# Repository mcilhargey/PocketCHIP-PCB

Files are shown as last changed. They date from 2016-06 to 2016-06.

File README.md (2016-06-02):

# Source Files
PocketC.H.I.P. is designed using Eagle CAD!
# PocketCHIP-PCB

PocketC.H.I.P. = v1.0

#License
<br />This work is licensed under a <a rel="license" href="http://creativecommons.org/licenses/by-sa/3.0/us/">Creative Commons Attribution-ShareAlike 3.0 United States License</a>.

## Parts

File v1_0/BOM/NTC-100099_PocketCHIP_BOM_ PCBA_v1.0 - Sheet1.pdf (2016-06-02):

| | | | PCBA Components
NTC PN | QTY | PARTS | VALUE | DESCRIPTION | FOOTPRINT | TOLERANCE | MFG | MFG Part Number
100313 | 2 | R1, R9 | 100K | RES THICK FILM SMD 100K Ohm 1/16W 5% RoHS 0603 | R0603 | ±5% | YAGEO | RC0603JR-07100KL
100314 | 6 | C2, C3, C6, C8, C9, C10 | 0.1uF | CAP CER 0.1UF 16V X7R 0603 | C0603 | ±10% | YAGEO | CC0603KRX7R7BB104
100315 | 3 | C4, C5, C7 | 10uF | CAP CER 10UF 50V X5R 1206 | C1206 | ±10% | SAMSUNG | CL31A106KBHNNNE
100318 | 2 | R7, R11 | 10K | RES SMD 10K OHM 5% 1/10W 0603 | R0603 | ±5% | PANASONIC | ERJ-3GEYJ103V
100319 | 1 | R3 | 11.5K | RES SMD 11.5K OHM 1% 1/10W 0603 | R0603 | ±1% | YAGEO | RC0603FR-0711K5L
100333 | 1 | R2 | 196K | RES SMD 196K OHM 1% 1/10W 0603 | R0603 | ±1% | YAGEO | RC0603FR-07196KL
100321 | 7 | R4, R5, R6, R10, R12, R16, R17 | 4.7K | RES SMD 4.7K OHM 5% 1/10W 0603 | R0603 | ±5% | PANASONIC | ERJ-3GEYJ472V
100323 | 1 | C1 | 220pF | CAP CER 220PF 50V NPO 0603 | C0603 | ±5% | YAGEO | CL10C221JB8NNNC
100332 | 1 | R13 | 1.2K | RES SMD 1.2K OHM 5% 1/10W 0603 | R0603 | ±5% | YAGEO | RC0603JR-071K2L
100250 | 2 | U13, U14 | 98401-801-40LF | Bergstik 40pin Board Guide Header | Headers | - | FCI | 带柱2*20pin贴片
100191 | 1 | U3 | DS2431P | IC, 1024-Bit, 1-Wire EEPROM, TSOC6 | TSOC6 | - | MAXIM | DS2431P+T&R
100220 | 1 | X1 | FH12-40S-0.5SH | CON ffc smd, bottom contact 40pos, 0.50mm R/A | FFC | - | FCI | 国产fpc 0.5 40pin
100193 | 1 | U1 | LMR62421 | dc/dc step up, 2.1A, 1.6mhz, SOT-23-5 | SOT23-5 | - | TI | LMR62421XMFE/NOPB
100195 | 1 | J3 | S2B-PH-SM4-TB | 2 pin con, 2MM RA, SMD | S2B-PH-SM4-TB | - | JST | 国产ph2.0
100196 | 1 | L1 | SRN6045-100M | power inductor 10uH 2.5A 58.6 mohm | SRN6045 | ±20% | BOURNS | 国产SPN6045-100M
100197 | 1 | U2 | TCA8418RTWR | Keypad/IO I2C expander, 8 rows 10 columns | WQFN24 | - | TI | TCA8418RTWR
100198 | 1 | D1 | B240A | DIODE SMD General Purpose 400V 1A 1.4W RoHS DO-214A | DO-214AC | - | DIODES | B240A-13-F
100338 | 17 | ESD1-17 | SESD3.3 | TVS DIODE 3.3VWM 10.9VC SOD523 | SOD523 | | - | SESD5Z3.3
100329 | 2 | Q3, Q4 | dmg3415u | MOSFET P-CH 20V 3.7A SOT23-3 | SOT-23-3 | - | DIODES | DMG3415U
100331 | 1 | Q1 | PDTC114YU | TRANS PREBIAS PNP 200MW UMT3 | SOT-323 | - | NXP | PDTC114YU115
100330 | 1 | Q2 | PDTA114YU115 | TRANS PREBIAS NPN 200MW UMT3 | SOT-323 | - | NXP | PDTA114YU115

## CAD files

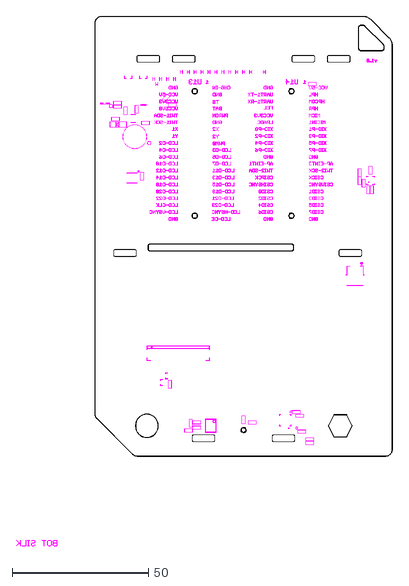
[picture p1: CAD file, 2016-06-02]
v1_0/DXF/PocketCHIP-v1.0.dxf
138.3 x 194.8

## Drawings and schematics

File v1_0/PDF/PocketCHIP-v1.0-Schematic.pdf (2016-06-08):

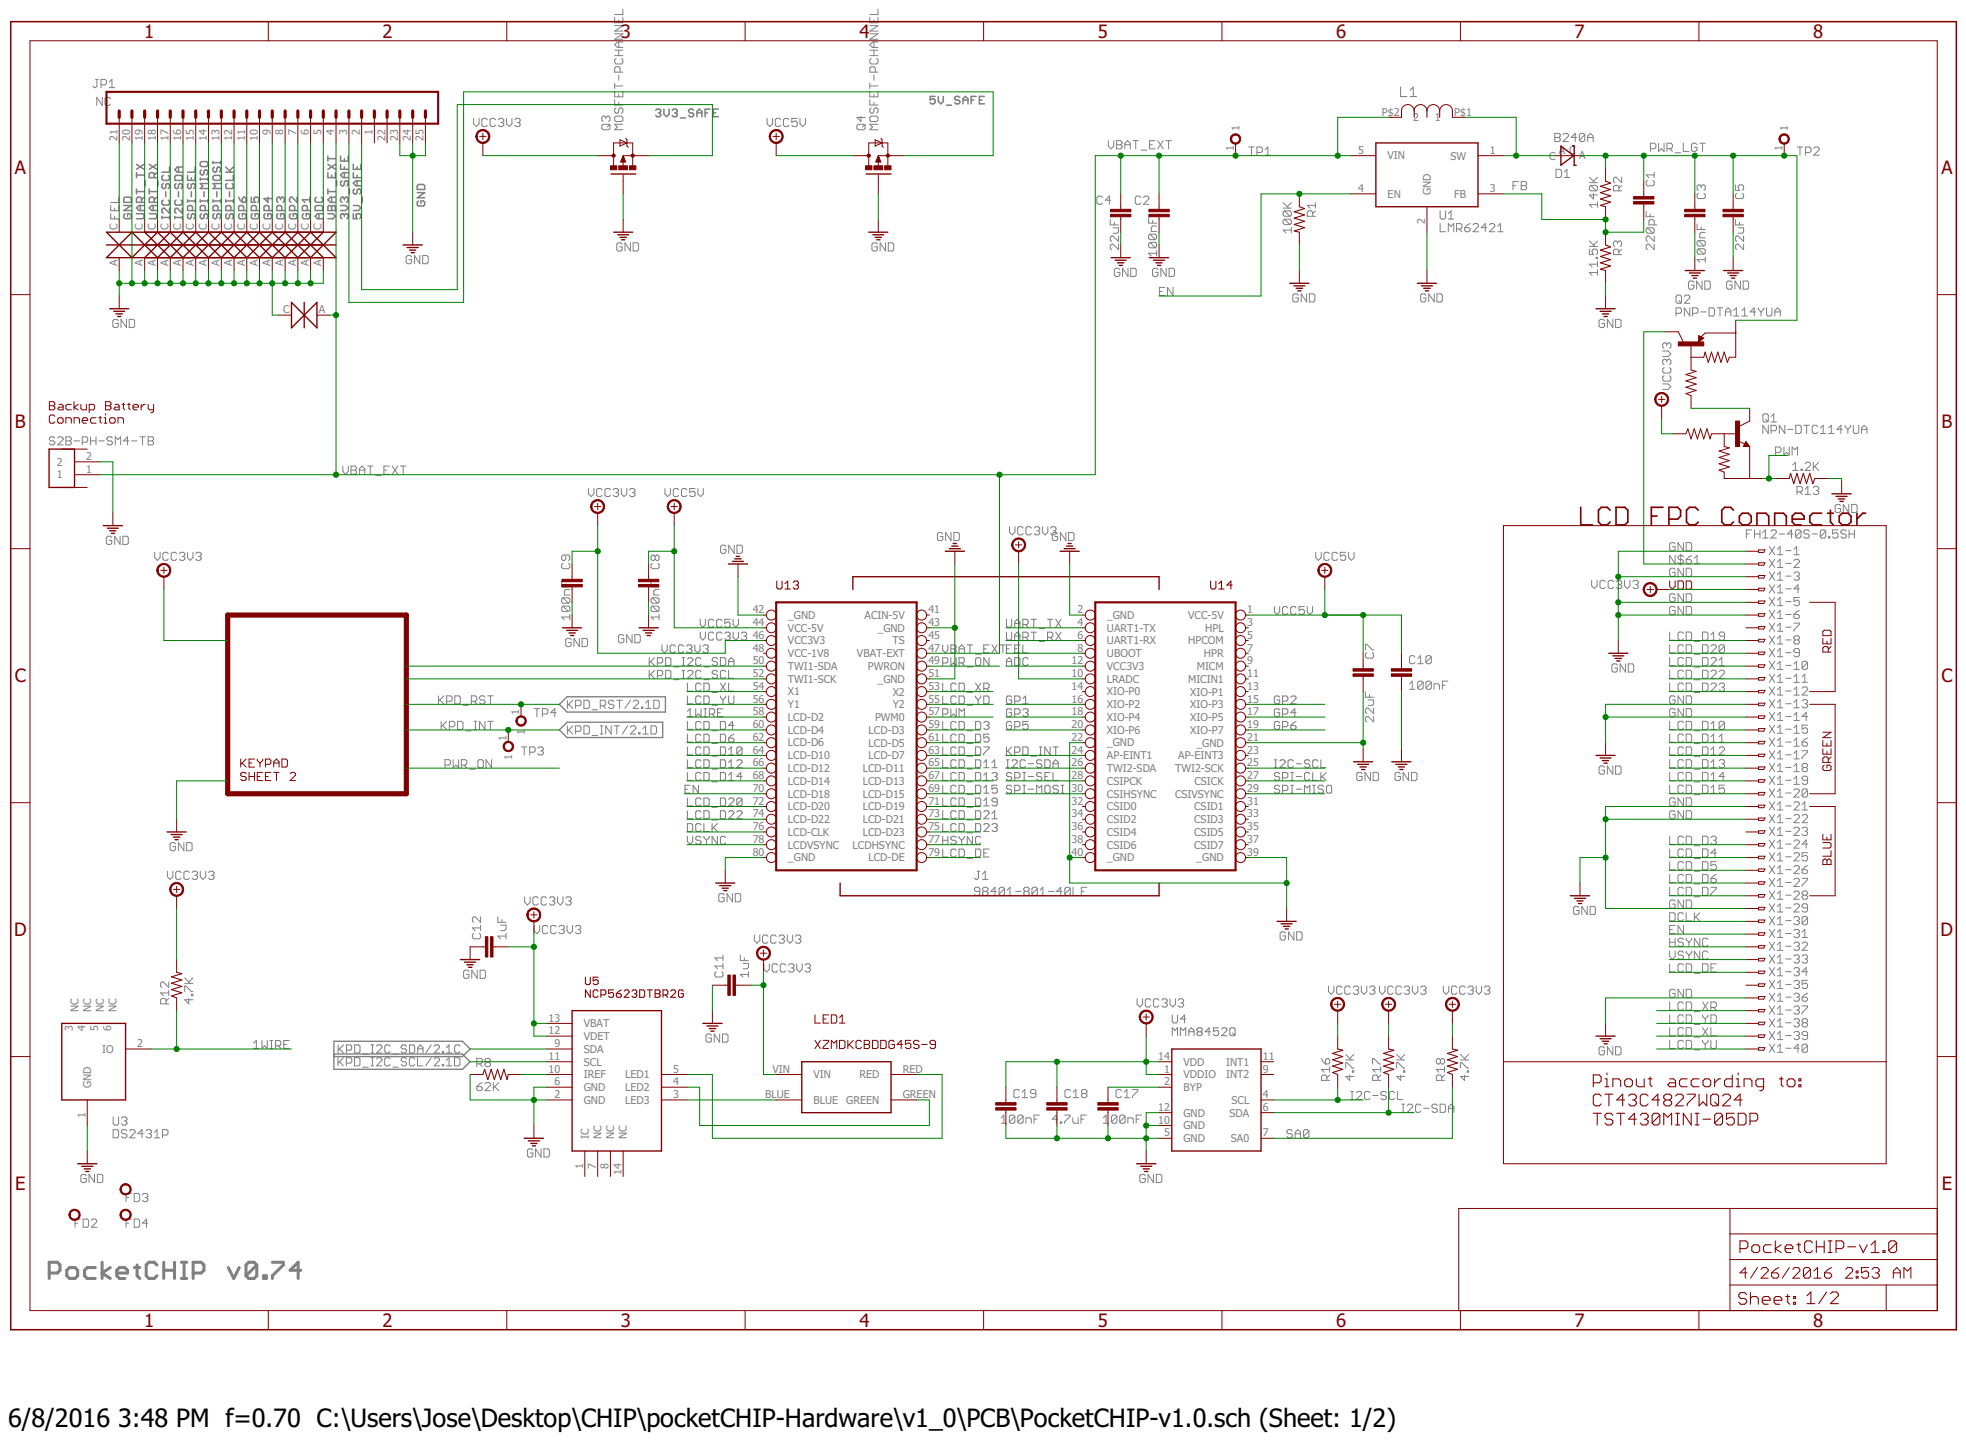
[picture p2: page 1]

6/8/2016 3:48 PM f=0.70 C:\Users\Jose\Desktop\CHIP\pocketCHIP-Hardware\v1_0\PCB\PocketCHIP-v1.0.sch (Sheet: 1/2)

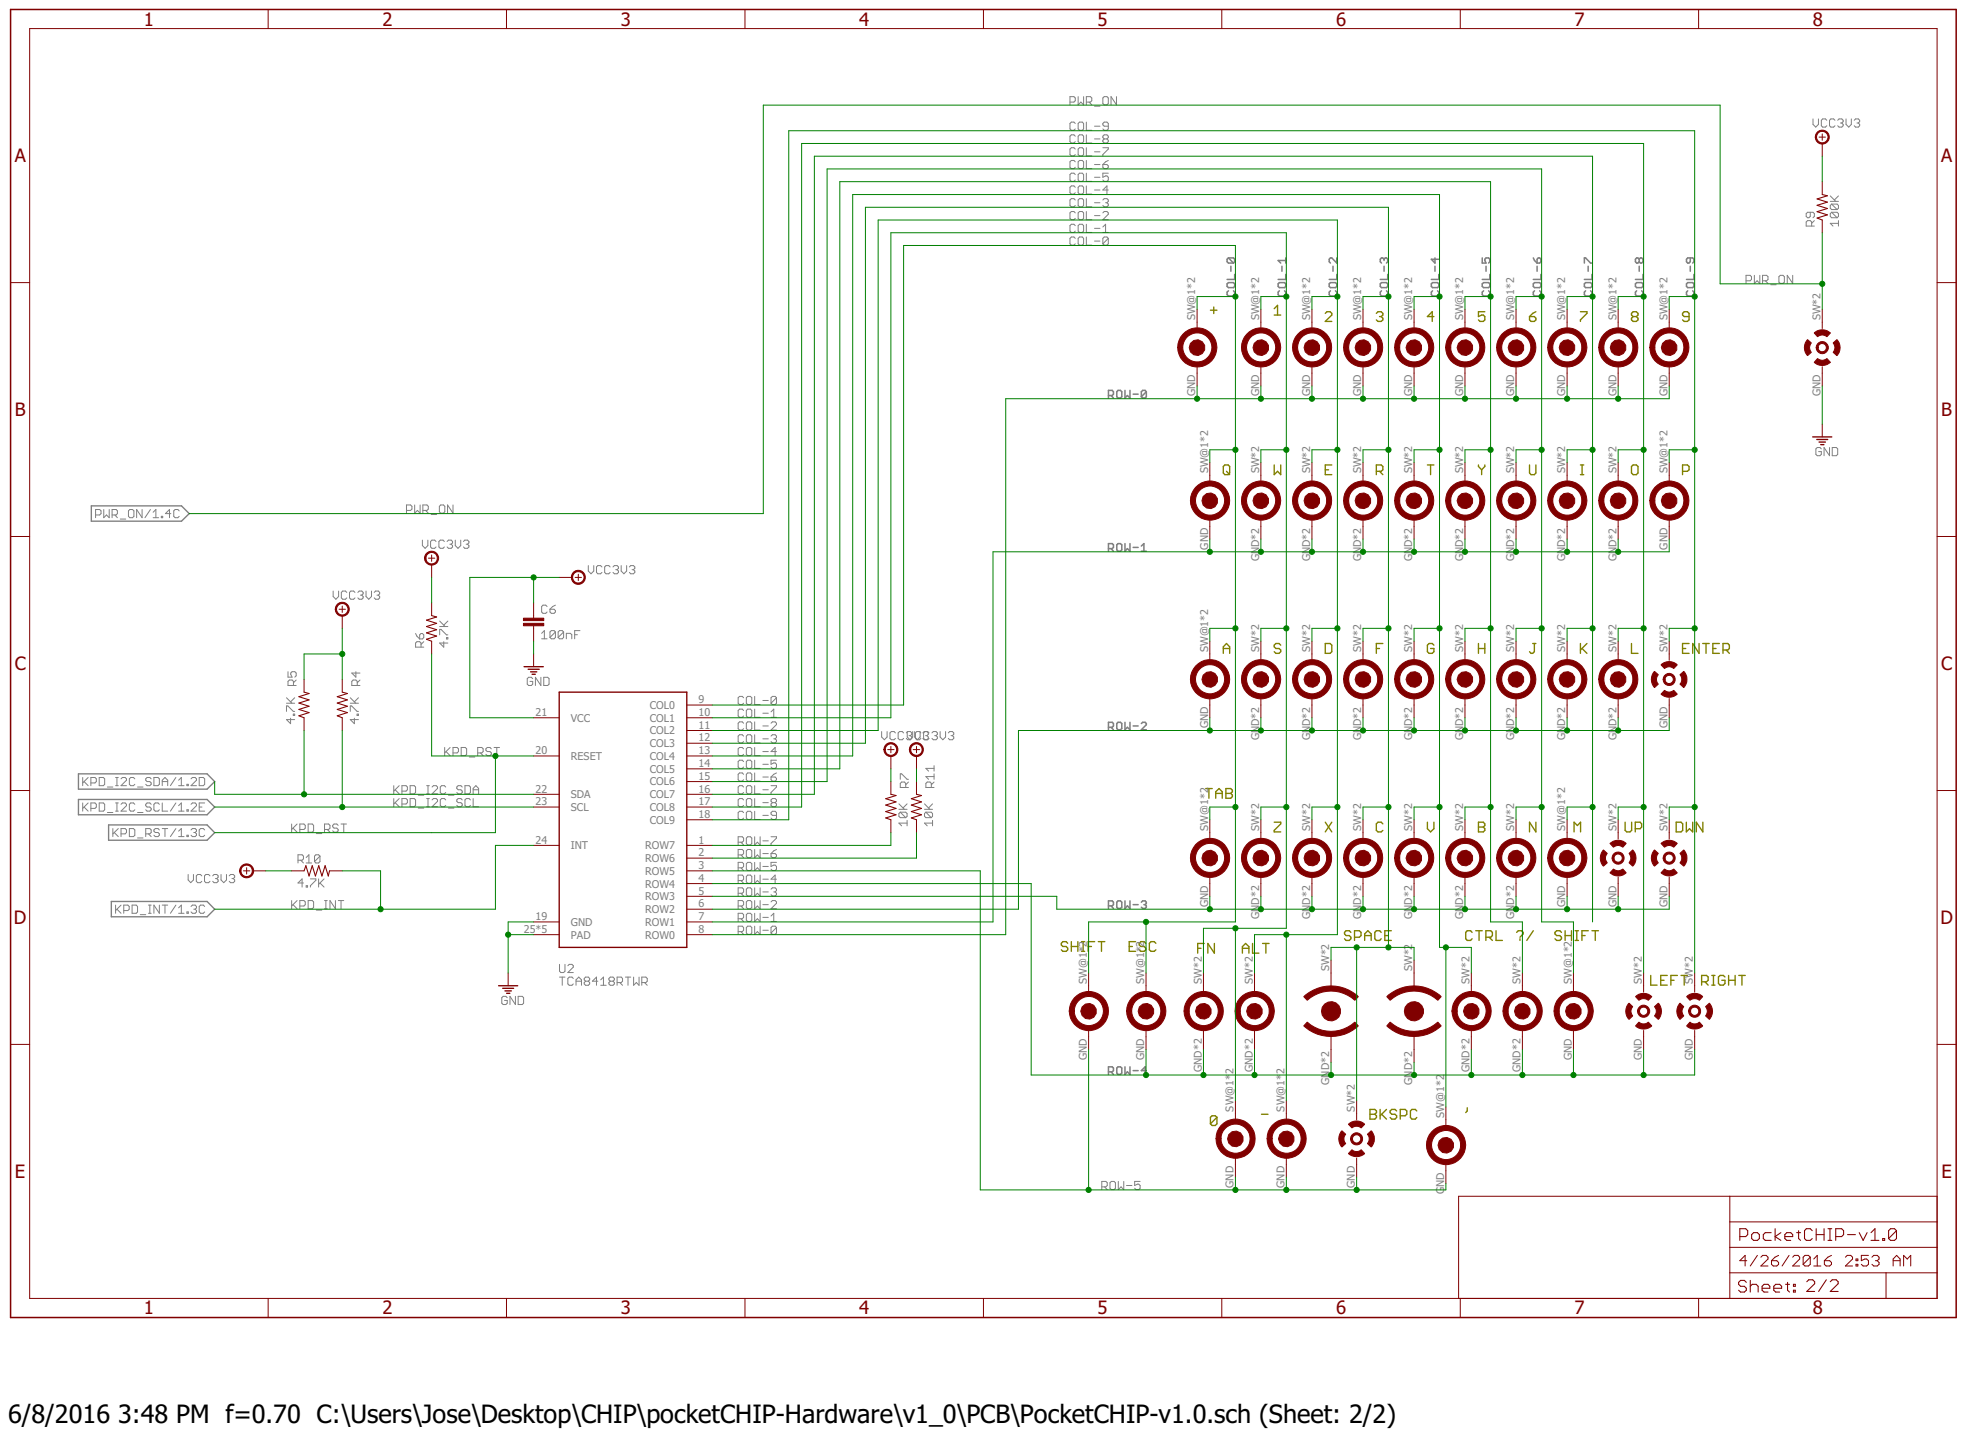
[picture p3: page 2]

GND SW@1*2 GND SW@1*2 GND SW@1*2 GND SW@1*2 GND SW@1*2 GND SW@1*2 GND SW@1*2 GND SW@1*2 GND SW@1*2 GND SW@1*2 GND SW@1*2

GND*2 SW*2 GND*2 SW*2 GND*2 SW*2 GND*2 SW*2 GND SW@1*2 GND SW@1*2

GND*2 SW*2

10 COL2
11 COL3
12 COL4
13 COL5
14 COL6
15 COL7

GND SW@1*2 GND*2 SW*2

GND*2 SW*2 GND*2 SW*2 GND*2 SW*2

GND SW*2 GND SW*2

5 ROW2
6 ROW1
7 ROW0

GND*2 SW*2 GND SW@1*2

6/8/2016 3:48 PM f=0.70 C:\Users\Jose\Desktop\CHIP\pocketCHIP-Hardware\v1_0\PCB\PocketCHIP-v1.0.sch (Sheet: 2/2)

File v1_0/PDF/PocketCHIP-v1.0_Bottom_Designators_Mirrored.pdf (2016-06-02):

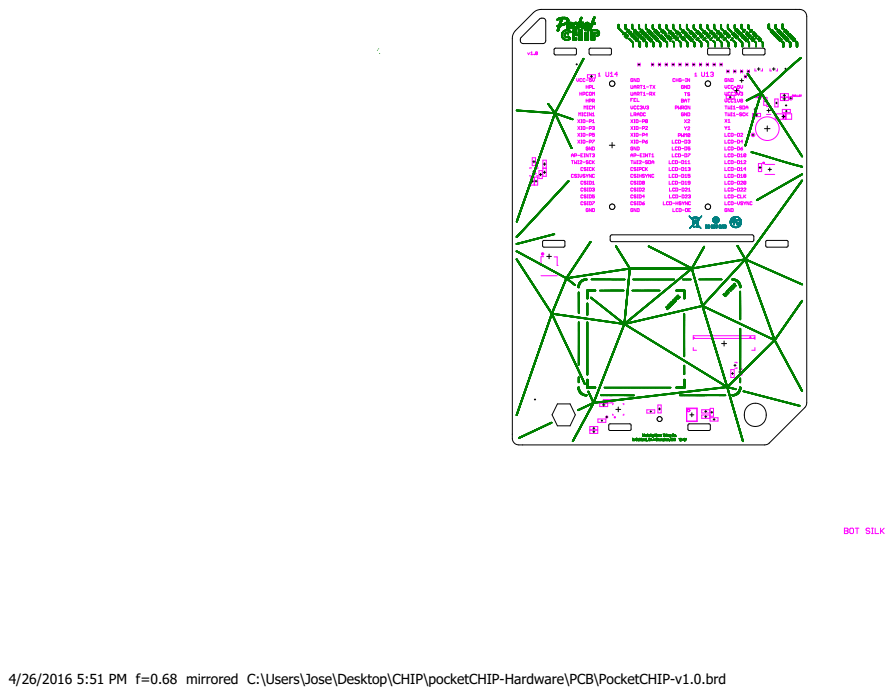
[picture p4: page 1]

4/26/2016 5:51 PM f=0.68 mirrored C:\Users\Jose\Desktop\CHIP\pocketCHIP-Hardware\PCB\PocketCHIP-v1.0.brd

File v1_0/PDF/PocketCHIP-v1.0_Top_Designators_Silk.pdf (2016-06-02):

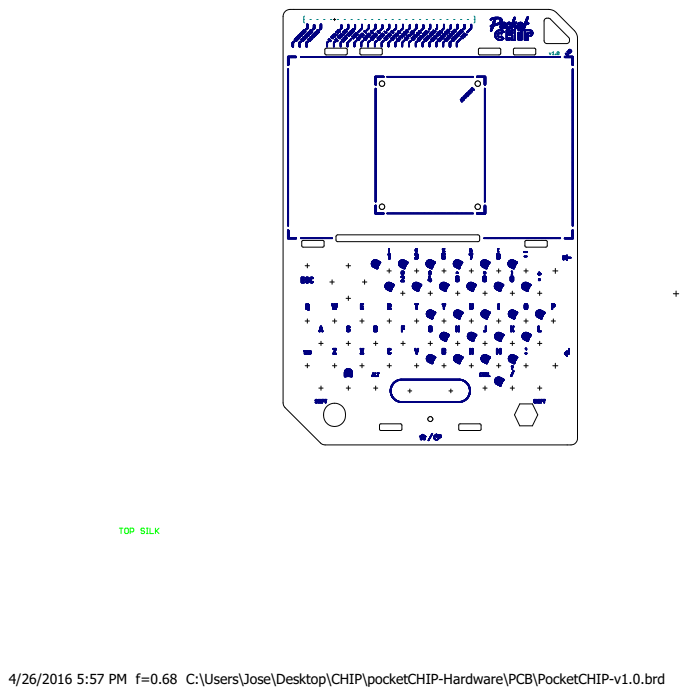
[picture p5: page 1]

4/26/2016 5:57 PM f=0.68 C:\Users\Jose\Desktop\CHIP\pocketCHIP-Hardware\PCB\PocketCHIP-v1.0.brd

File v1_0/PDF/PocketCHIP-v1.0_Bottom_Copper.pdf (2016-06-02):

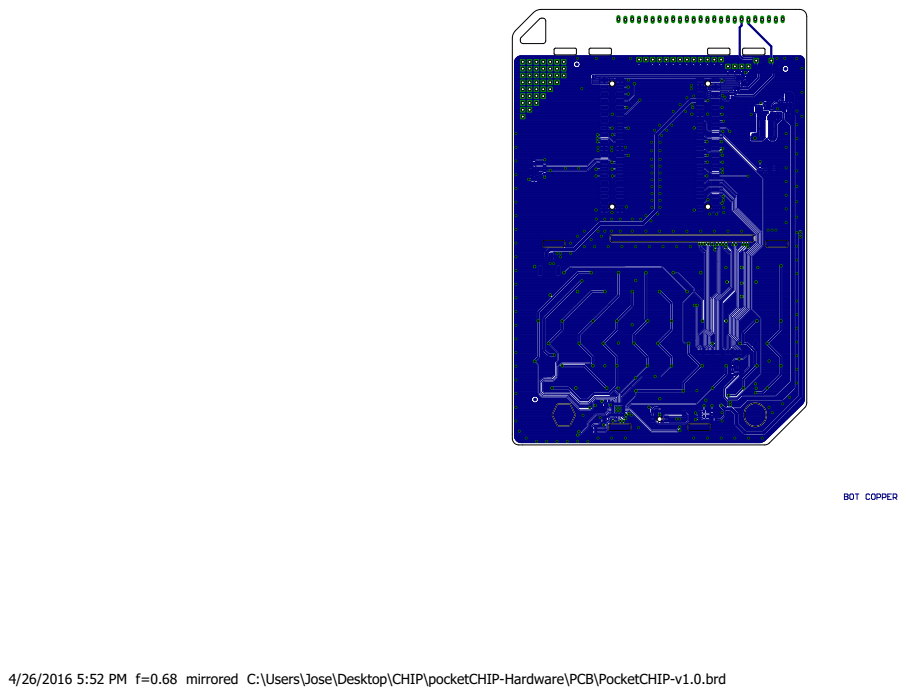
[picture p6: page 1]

4/26/2016 5:52 PM f=0.68 mirrored C:\Users\Jose\Desktop\CHIP\pocketCHIP-Hardware\PCB\PocketCHIP-v1.0.brd

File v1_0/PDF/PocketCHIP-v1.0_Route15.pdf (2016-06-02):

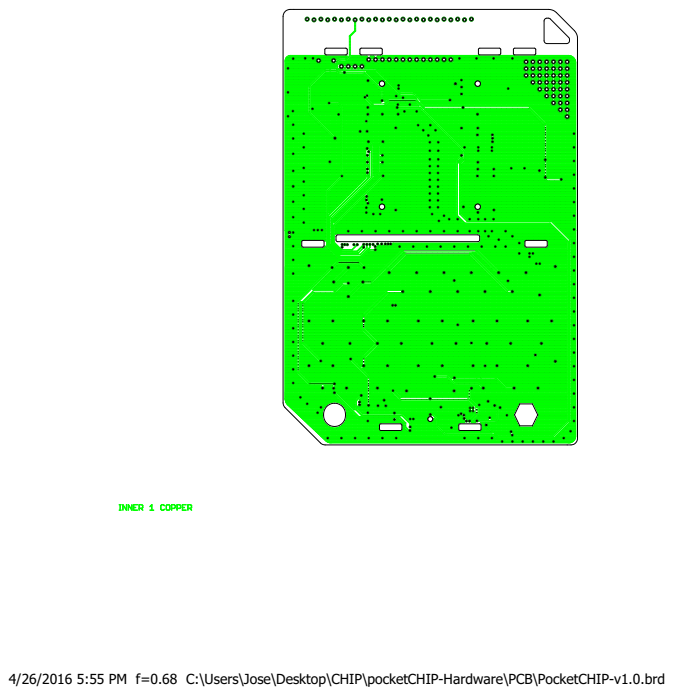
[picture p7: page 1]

4/26/2016 5:55 PM f=0.68 C:\Users\Jose\Desktop\CHIP\pocketCHIP-Hardware\PCB\PocketCHIP-v1.0.brd

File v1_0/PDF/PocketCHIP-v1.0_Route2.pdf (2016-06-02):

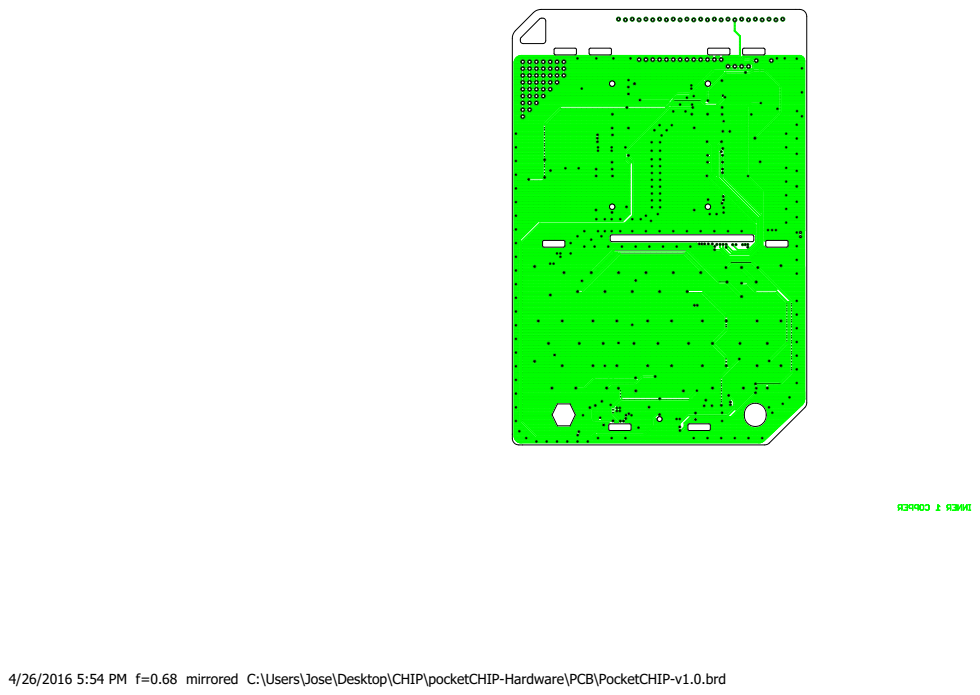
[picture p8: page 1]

4/26/2016 5:54 PM f=0.68 mirrored C:\Users\Jose\Desktop\CHIP\pocketCHIP-Hardware\PCB\PocketCHIP-v1.0.brd

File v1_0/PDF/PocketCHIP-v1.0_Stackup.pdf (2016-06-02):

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

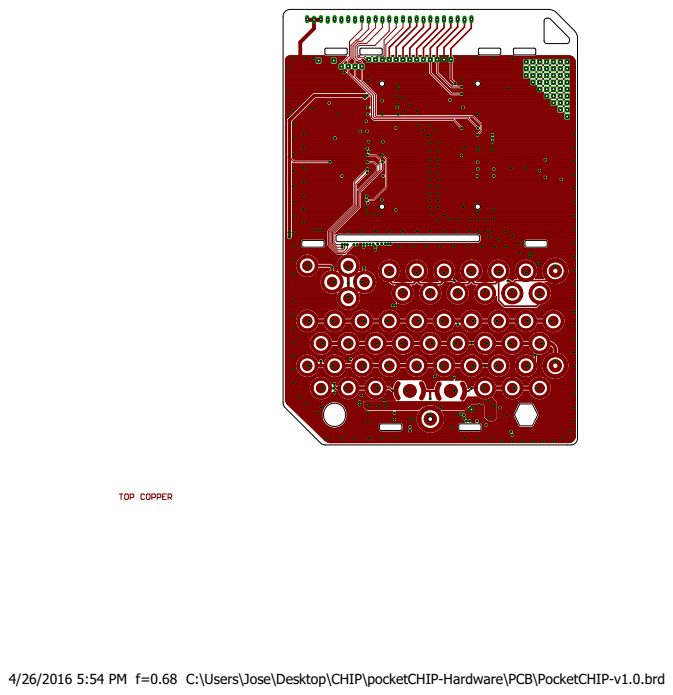
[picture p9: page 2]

4/26/2016 5:54 PM f=0.68 C:\Users\Jose\Desktop\CHIP\pocketCHIP-Hardware\PCB\PocketCHIP-v1.0.brd

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

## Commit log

2016-06-02 v1.0 Release, actual credit to @bleepbloop
    [NTC-100099_PocketCHIP_BOM_ PCBA_v1.0.xlsx, PocketCHIP-v1.0.dxf, PocketCHIP-v1.0.sch]
2016-06-08 adding missing schematic
